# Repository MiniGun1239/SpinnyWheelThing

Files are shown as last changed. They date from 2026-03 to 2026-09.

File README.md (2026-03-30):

# Spinny Wheel Thing
A very spinning Steering wheel running on rpi pico

## Intro
This is my attempt at making a sim wheel with (sadly) no FFB.

# Steering Assembly & Electronics Bill of Materials

| Name | Purpose | Qty | Total (USD) | Distributor | Link |
|:---|:---|:----|:---|:---|:---|
| **Supports** | To hold the bolts in place together | 1 | $10.00 | Hardware Store / 3D Printed | - |
| **Gear** | Gearing down Pot (1:3.1 ratio) | 1 | $4.00 | 3D Printed | - |
| **Bolt** | Connected to steering wheel and gear | 2 | $9.09 | Hardware Store / 3D Printed | [Link to listing](https://www.mcmaster.com/93325A422/) |
| **M2 Screws** | To mount things | 8 | $0.28 | Hardware Store | [Link to listing](https://www1.mcmaster.com/99461A914/) |
| **Washer** | To ensure easier turning / reduce friction | 4 | $5.71 | Hardware Store / 3D Printed | [Link to listing](https://www.mcmaster.com/91701A622/) |
| **Pulley Belt** | Connecting the 2 gears without backlash | 1 | $26.43 | Hardware Store | [Link to listing](https://www1.mcmaster.com/6484K159/) |
| **Nut** | Stopping steering wheel from over-turning  | 4 | $0.25 | Hardware Store / 3D Printed | [Link to listing](https://www.mcmaster.com/97700A160/) |
| **Ball Bearing** | To ensure smooth turning | 5 | $2.00 | Amazon | [Link to listing](https://www.amazon.ae/gp/product/B0G1FX4NN2) |
| **Wires** | Connecting components together | 1 | $5.50 | Besomi | [Link to listing](https://besomi.com/ae_en/premium-dupont-wire-kit-for-arduino-and-diy-projects-120pcs-20cm-multicolored.html) |
| **Potentiometer** | Getting rotation data | 1 | $2.00 | Besomi | [Link to listing](https://besomi.com/ae_en/potentiometer-b10k.html) |
| **Raspberry Pi Pico H** | Brains of the operation | 1 | $8.50 | Besomi | [Link to listing](https://besomi.com/ae_en/raspberry-pi-pico-h.html) |

**Total Estimated Cost: ~$80.00**  
_(Price is subject to change (possibly lower), this figure is purely an estimate.)_

# Wiring Diagram

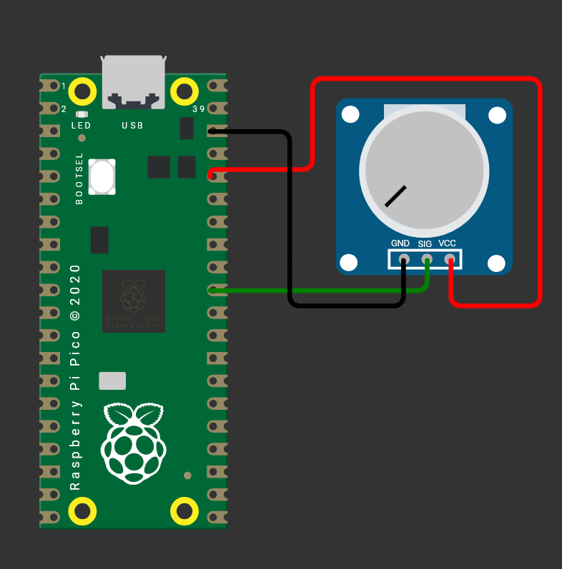
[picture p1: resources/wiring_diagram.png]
Wiring Diagram.png


# Project pictures

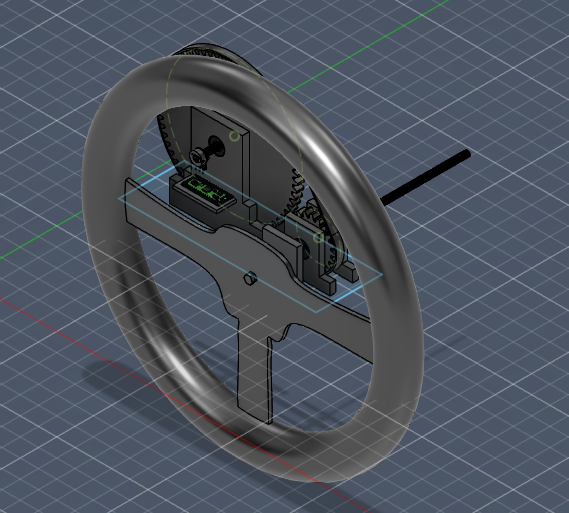
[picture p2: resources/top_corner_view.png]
Top Corner View of CAD Model


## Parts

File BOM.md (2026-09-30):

# Steering Wheel — bill of materials

<!-- Generated by Half Life from project cmuoe9uac000001njx4zqg897. Edits here are overwritten on the next sync. -->
<!-- Generated: 1970-01-01T00:00:00.000Z -->

> [!NOTE]
> This parts list is mirrored from [Half Life](https://halflife.hackclub.com). Editing it here will not change the platform's copy, and the next sync overwrites this file.

| Week | Tier | Parts funding |
| --- | --- | --- |
| Warm-up | Tier 1 | $30.00 |

_No parts listed yet._

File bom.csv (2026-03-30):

Name | Purpose | Qty | Total (USD) | Distributor | Link
Supports (Block of wood or 3D Printed) | To hold the bolts in place together | 1 | $10.00 | Hardware Store or 3D Printed | -
Gear | Gearing down the Potentiometer so that 900 degrees of the wheel will turn the potentiometer 280 degrees (1:3.1 ratio) | 1 | $4.00 | 3d Printed | -
Bolt | Connected to the steering wheel and the gear to drive the belt system | 2 | $9.09 | Hardware Store or 3d Printed | https://www.mcmaster.com/93325A422/
M2 Screws | To Mount things | 8 | $0.28 | Hardware Store | https://www1.mcmaster.com/99461A914/
Washer | To ensure easier turning so that the nuts wont be moving due to buildup of friction | 4 | $5.71 | Hardware Store or 3d Printed | www.mcmaster.com/91701A622/
Pulley Belt | Connecting the 2 gears without backlash | 1 | $26.43 | Hardware Store | https://www1.mcmaster.com/6484K159/
Nut | Stopping the steering wheel from turning too much and snapping the wiper + more stuff | 4 | $0.25 | Hardware Store or 3d Printed | https://www.mcmaster.com/97700A160/
Ball Bearing | To ensure smooth turning | 5 | $2.00 | Amazon | https://www.amazon.ae/gp/product/B0G1FX4NN2
Wires | Connecting components together | 1 | $5.50 | Besomi | https://besomi.com/ae_en/premium-dupont-wire-kit-for-arduino-and-diy-projects-120pcs-20cm-multicolored.html
Potentiometer | Getting rotation data | 1 | $2.00 | Besomi | https://besomi.com/ae_en/potentiometer-b10k.html
Raspberry Pi Pico H | Brains of the operation | 1 | $8.50 | Besomi | https://besomi.com/ae_en/raspberry-pi-pico-h.html

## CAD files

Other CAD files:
Resources/Wheel thing 2.0.f3z

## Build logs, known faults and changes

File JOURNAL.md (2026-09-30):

# Steering Wheel — devlog

<!-- Generated by Half Life from project cmuoe9uac000001njx4zqg897. Edits here are overwritten on the next sync. -->
<!-- Generated: 1970-01-01T00:00:00.000Z -->

> [!NOTE]
> This devlog is mirrored from [Half Life](https://halflife.hackclub.com). Editing it here will not change the platform's copy, and the next sync overwrites this file.

> A steering wheel (just a potentiometer with somewhat custom firmware)

| Week | Tier | Hours logged | Entries |
| --- | --- | --- | --- |
| Warm-up | Tier 1 | 0h | 0 |

_No entries logged yet._

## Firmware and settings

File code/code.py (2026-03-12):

import board
import analogio
import usb_hid
import sys
import time

# --- SYSTEM CONFIG ---
TEST = True

# --- USAGE SETTING ---
CENTER_DEADZONE = 100

if TEST:
    print('[DEBUG] IN TEST MODE')

# --- SETUP ---
steeringWheel = None # Initialize gamepad first

# Set report as a byte array. As set by boot.py
report = bytearray(4)

# Get gamepad from devices
for thing in usb_hid.devices:
    if TEST:
        report_id = getattr(thing, 'report_id', None)
        print('[DEBUG] Device found: ', thing, "Report ID:", report_id)
    # preset in boot.py
    if hasattr(thing, 'report_id') and thing.report_id == 4:
        steeringWheel = thing
        break

# If boot.py got changed somehow
if not steeringWheel:
    print('No gamepad found, you messed up')
    sys.exit()

# Get the potentiometer (Pin 31 / GP26 / ADC0)
potentiometer = analogio.AnalogIn(board.GP26) # Pin 31

# --- CONSTANTS ---
SIXTEEN_BIT_INTEGER_LIMIT = 65535 # (2**16 - 1) Value from Potentiometer is sent as 16 bit value
SIXTEEN_BIT_INTEGER_LIMIT_MIN = -32768
SIXTEEN_BIT_INTEGER_LIMIT_MAX = 32767

# More math stuff
HEADROOM_RATIO = 280 / 300 # If Total rotation is 300 degrees. Headroom so that the potentiometer doesnt break
# HEADROOM_RATIO = 250 / 270 # If Total rotation is 270 degrees. Headroom so that the potentiometer doesnt break.
ACTIVE_RANGE = int(SIXTEEN_BIT_INTEGER_LIMIT * HEADROOM_RATIO)
OFFSET = (SIXTEEN_BIT_INTEGER_LIMIT - ACTIVE_RANGE) // 2 # find the unused ends size

if TEST:
    print('[DEBUG] 16 Bit Integer Limit: ', SIXTEEN_BIT_INTEGER_LIMIT)
    print('[DEBUG] Headroom Ratio: ', HEADROOM_RATIO)
    print('[DEBUG] Active Range: ', ACTIVE_RANGE)
    print('[DEBUG] Offset: ', OFFSET)

MIN_LIMIT = 0 + OFFSET
MAX_LIMIT = SIXTEEN_BIT_INTEGER_LIMIT - OFFSET

if TEST:
    print('[DEBUG] MIN_LIMIT: ', MIN_LIMIT)
    print('[DEBUG] MAX_LIMIT: ', MAX_LIMIT)

while True:
    # Read potentiometer
    raw_value = potentiometer.value

    if TEST:
        print('[DEBUG] Potentiometer Raw value: ', raw_value)

    # Restrict the values so that the nut and bolt mechanism is actually correctly placed
    new_value = max(MIN_LIMIT, min(MAX_LIMIT, raw_value))

    if TEST:
        print('[DEBUG] New value: ', new_value)

    # Mapping the new value to a 16-bit integer (-32767 to 32767)
    steer_value = int((((new_value - MIN_LIMIT) / ACTIVE_RANGE) * 65534) - 32767)

    if TEST:
        print('[DEBUG] Steer Value: ', steer_value)

    # Ensure steering is within 16-bit integer limit, and is an integer
    steering = int(max(SIXTEEN_BIT_INTEGER_LIMIT_MIN, min(SIXTEEN_BIT_INTEGER_LIMIT_MAX, steer_value)))

    if TEST:
        print('[DEBUG] Steering: ', steering)

    # Split mapping these two bytes of data
    # report[2] is Low Byte, so rightmost byte. 'and' (&) operator replaces the first byte with 0xFF (11111111)
    # and gets ignored, only the right byte gets sent
    report[2] = steering & 0xFF

    if TEST:
        print('[DEBUG] Report low byte: ', report[2])

    # report[3] is the High Byte, so left most byte. same as report[2], however, the '>>' operator moves the whole
    # two bytes to the right, and sends the new right byte which was originally the left byte. 0xFF does the same thing.
    report[3] = (steering >> 8) & 0xFF

    if TEST:
        print('[DEBUG] Report high byte: ', report[3])

    # sends the info to pc
    try:
        steeringWheel.send_report(report)
        if TEST:
            print('[DEBUG] Report sent successfully')
    except OSError:
        if TEST:
            print('[DEBUG] Report failed to send')
        pass

    # Apparently this helps somehow? 100hz refresh, 10ms delay
    if TEST:
        time.sleep(1)
        continue

    time.sleep(0.01)

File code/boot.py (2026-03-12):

import usb_hid

# THIS IS WRITTEN BASED ON ADAFRUIT's CODE
# While this is almost something completely different, I did start with ADAFRUIT's code
# Need to give credit where credit is due
# https://learn.adafruit.com/customizing-usb-devices-in-circuitpython/hid-devices#custom-hid-devices-3096614-9

GAMEPAD_REPORT_DESCRIPTOR = bytes((
    0x05, 0x01,         # Usage Page (Generic Desktop Ctrls)
    0x09, 0x05,         # Usage (Steering Wheel)
    0xA1, 0x01,         # Collection (Application)
    0x85, 0x04,             # Report ID (4)
    0x05, 0x09,             # Usage Page (Button)
    0x19, 0x01,             # Usage Minimum (Button 1)
    0x29, 0x10,             # Usage Maximum (Button 16)
    0x15, 0x00,             # Logical Minimum (0)
    0x25, 0x01,             # Logical Maximum (1)
    0x75, 0x01,           # Report Size (1)
    0x95, 0x10,           # Report Count (16)
    0x81, 0x02,             # Input (Data,Var,Abs)
    0x05, 0x01,         # Usage Page (Generic Desktop Ctrls)
    0x16, 0x00, 0x80,       # Logical Minimum (-32768)
    0x26, 0xFF, 0x7F,       # Logical Maximum (32767)
    0x09, 0x30,         # Usage (X axis)
    0x75, 0x10,           # Report Size (16 bits)
    0x95, 0x01,           # Report Count (1 axis)
    0x81, 0x02,             # Input (Data,Var,Abs)
    0xC0
))

steeringWheel = usb_hid.Device(
    report_descriptor=GAMEPAD_REPORT_DESCRIPTOR,
    usage_page=0x01,            # Generic Desktop Control
    usage=0x05,                 # Steering Wheel
    report_ids=(4,),            # Descriptor uses report ID 4
    in_report_lengths=(4,),     # This sends 4 bytes in its report
    out_report_lengths=(0,),    # It does not receive any reports
)

usb_hid.enable(
    (
        usb_hid.Device.KEYBOARD,
        usb_hid.Device.MOUSE,
        usb_hid.Device.CONSUMER_CONTROL,
        steeringWheel
    )
)

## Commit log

2026-03-12 Added the firmware (Circuit Python) and the code, will update readme later.
2026-03-25 Added BOM
2026-03-25 Fixed BOM
2026-03-25 Added ting to BOM
2026-03-25 Added wiring diaram and cad model
2026-03-25 Updaed BOM
2026-03-25 added csv
    [bom.csv]
2026-03-25 added cad stuff
    [Wheel thing 2.0.f3z]
2026-03-30 updated bom
    [bom.csv]
2026-03-30 Updated CAD files
2026-03-30 Updated CAD files
    updated dirs
    updated readme
2026-09-30 Sync Steering Wheel from Half Life
